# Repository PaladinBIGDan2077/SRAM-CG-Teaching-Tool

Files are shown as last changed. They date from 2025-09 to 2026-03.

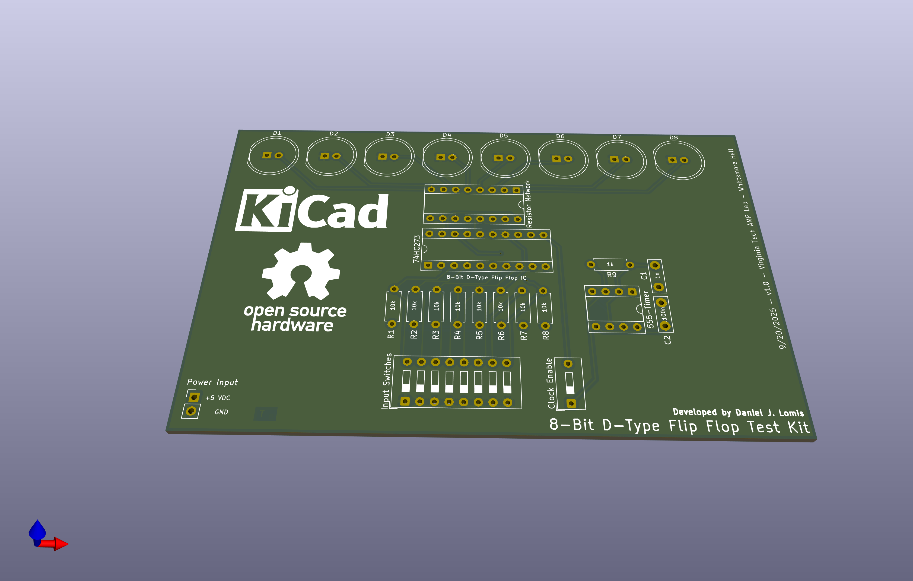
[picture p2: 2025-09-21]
KiCad/Practice/Practice-top.png

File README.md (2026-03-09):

## Members
Daniel J. Lomis, Computer Engineering: Chip-Scale Integration (May 2026)
dlomis1999@vt.edu

## Mentor
Professor Jason S. Thweatt

## Current Status
IN PROGRESS

## Project Overview

This project will demonstrate to the end-user how memory is used to store and read data within a computer, how changing BITs will have an effect on the output of a visualized character. while the unit itself will not be using a centralized processing unit instead the heart of the binary to ask you decoding will be controlled by a character generator ROM made by Fairchild semiconductor. The particular part is a 3257ADC from the late 1970s. The use of vintage components in this particular build helps to take away the layers of abstraction that computers now represent in modern day technology. By simplifying the underlying hardware that has the result of making the overall explanation of its functionality simpler. All plans were originally meant to include a set of early 1980s SRAM moudules. The need to switch to multiple education boards for the final product, made it clear that additional memory was needed as well as a more ample and stable supply of it.

## Educational Value Added

It provides insight to how character generator ROMs work, which were quite common in the days of early home computing. This will lead to a further understanding of ASCII based decoding. Storage of certain bits will allow the character rom to display individual characters on an LED Matrix, which will allow the viewer to write a message on screen letter by letter. A Binary Counter will be used to scroll through memory addresses, and a buffer will be used to display the current data to write to memory, as well as entry of a specific memory address.

## Tasks

Remaining tasks
 • research and implementation of a proper display method for the 8 x 8 matrix
 • research in limitation of the chosen memory modules
 • research and implementation of a binary input method for the memory
 • optional: an implementation to set and reset the memory counter to change specific memory areas that aren't linearly accessed

## Design Decisions

 • the board will be placed on a single PCB smaller than a sheet of standard letter paper
 • the device will be using a 16 VDC power supply going into the power connector on the board. The type of power supply and whether it will be USB-C based has yet to be determined.
 • 
## Design Misc

<!-- Your Text Here. You may work with your mentor on this later when they are assigned -->

## Steps for Documenting Your Design Process

<!-- Your Text Here. You may work with your mentor on this later when they are assigned -->

## BOM + Component Cost

VINTAGE Fairchild 3257ADC Character Generator ROM - $16.37
8X8 LED MATRIX - $10.86
VINTAGE AMD AM9101BPC SRAM Modules 256 x 4 BITS, (two used in series, two in parallel, to increase to 512 X 8 BITS) 512K RAM - $23.97

## Timeline

<!-- Your Text Here. You may work with your mentor on this later when they are assigned -->

## Useful Links

<!-- Your Text Here. You may work with your mentor on this later when they are assigned -->

## Log

<!-- Your Text Here. You may work with your mentor on this later when they are assigned -->

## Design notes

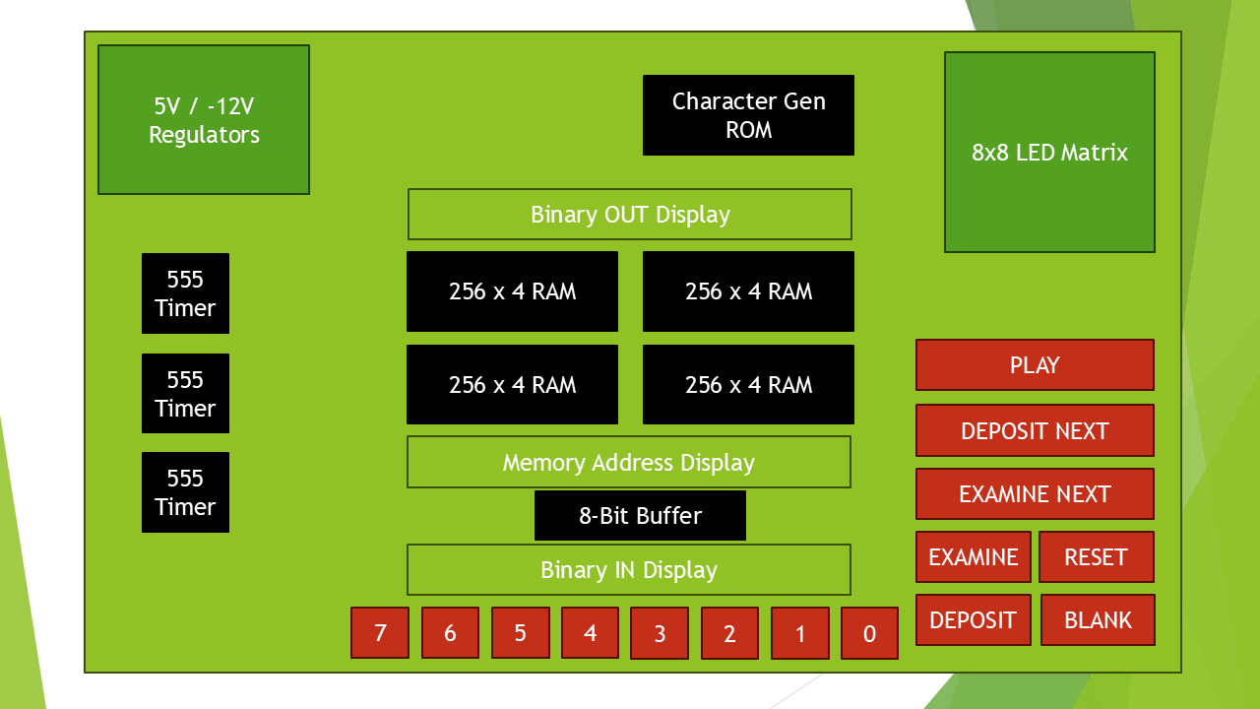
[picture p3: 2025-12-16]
hero.png

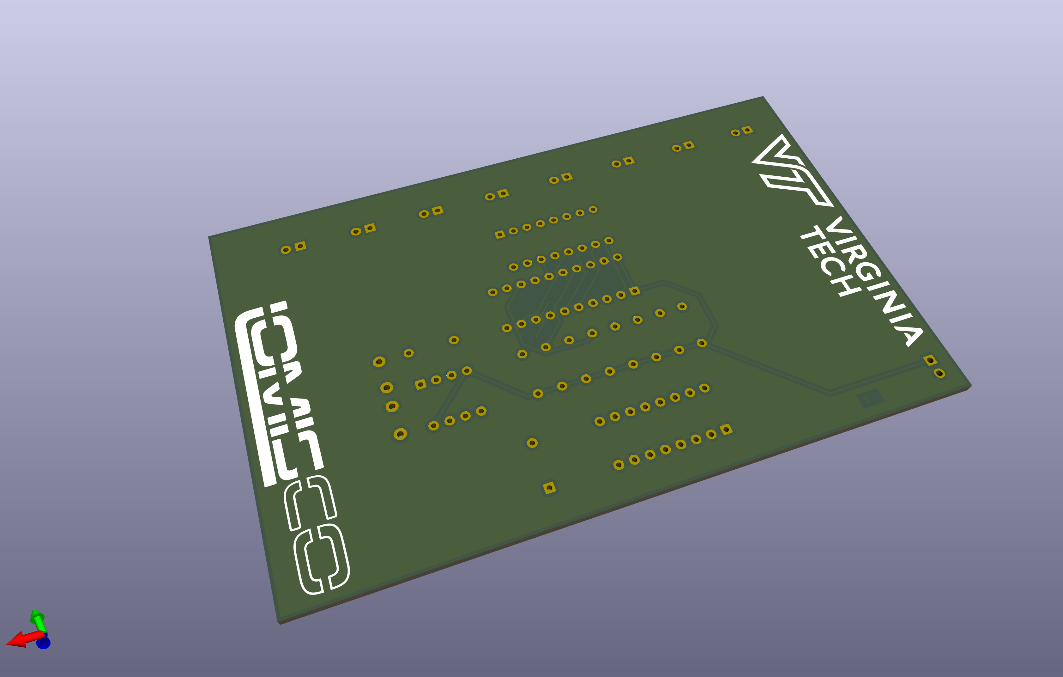
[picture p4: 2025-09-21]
KiCad/Practice/Practice-bottom.png

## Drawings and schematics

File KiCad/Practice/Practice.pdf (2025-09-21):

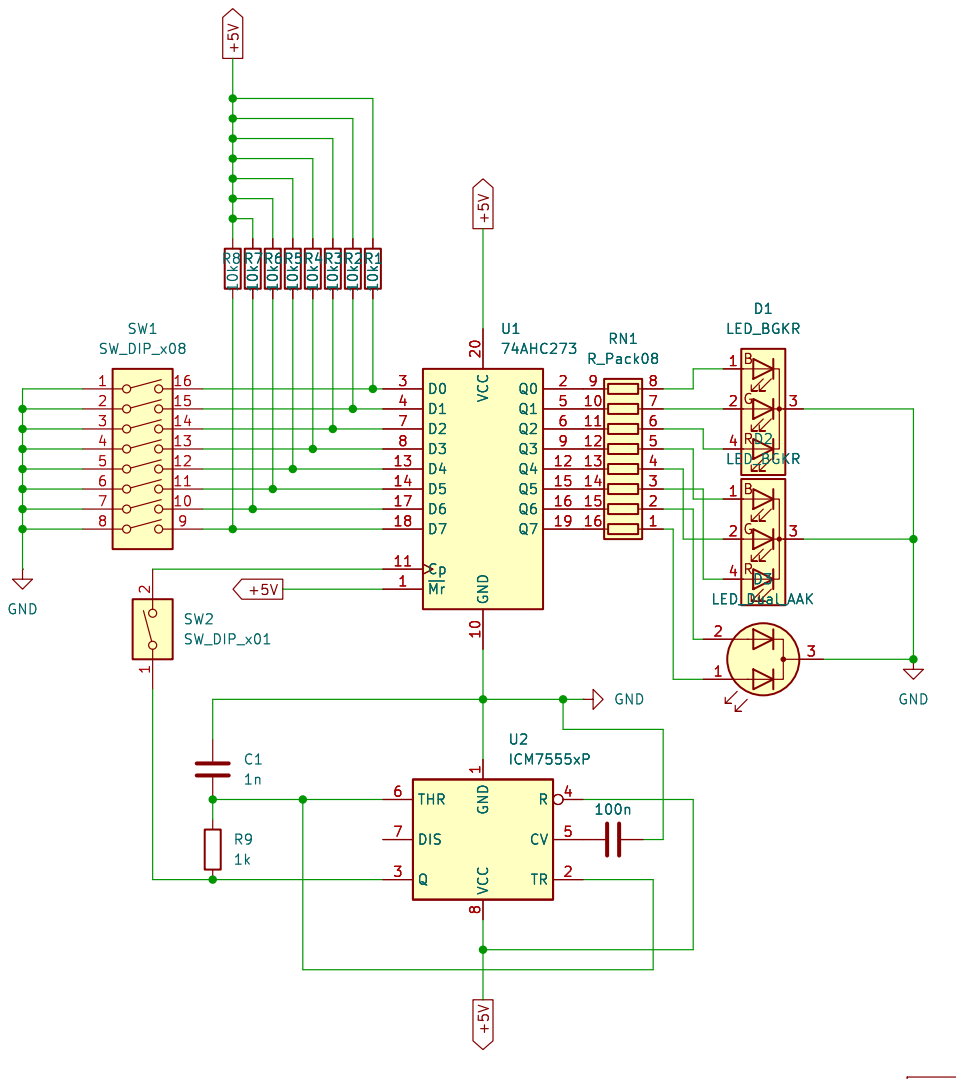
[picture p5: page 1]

10 10 | 7 7
11 11 | 6 6 | | 3 3
13 13 | 4 4 | 1 LED_BGKR LED_BGKR | D2
12 12 | 5 5

14 14 | 3 3
15 15 | 2 2
16 16 | 1 1

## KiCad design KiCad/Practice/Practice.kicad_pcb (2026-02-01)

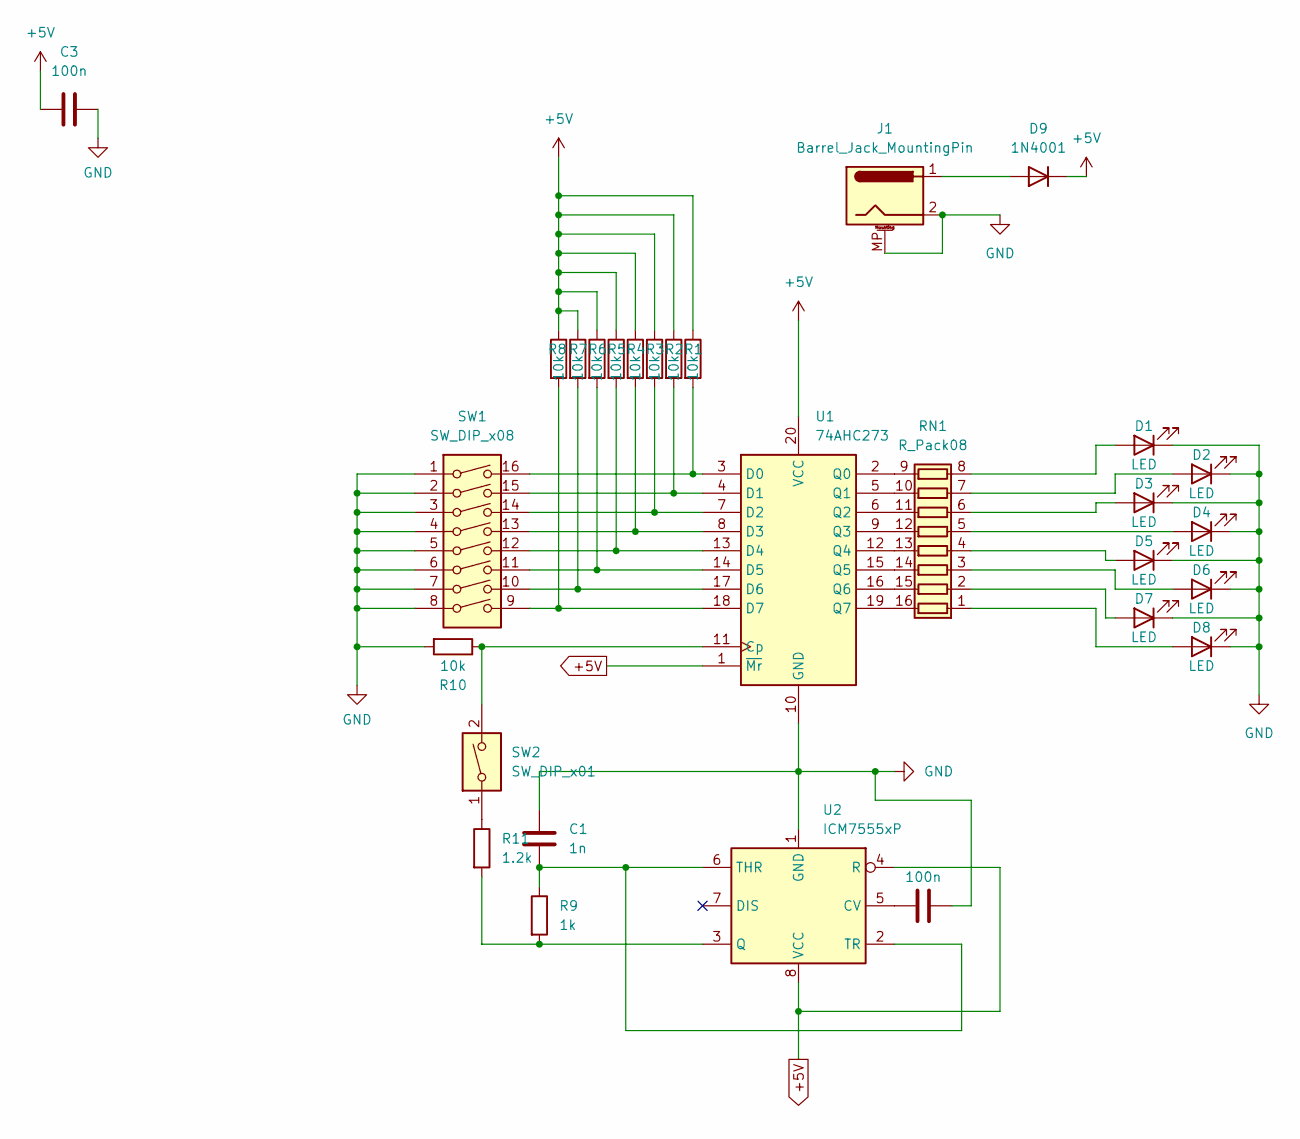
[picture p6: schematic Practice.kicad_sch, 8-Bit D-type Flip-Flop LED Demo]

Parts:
C1: 1n; C_Disc_D7.5mm_W2.5mm_P5.00mm
C2, C3: 100n; C_Disc_D7.5mm_W2.5mm_P5.00mm
D1, D2, D3, D4, D5, D6, D7, D8: LED; LED_D10.0mm
D9: 1N4001; D_DO-41_SOD81_P10.16mm_Horizontal
J1: Barrel_Jack_MountingPin; BarrelJack_CUI_PJ-063AH_Horizontal
R1, R2, R3, R4, R5, R6, R7, R8, R10: 10k; R_Axial_DIN0207_L6.3mm_D2.5mm_P7.62mm_Horizontal
R9: 1k; R_Axial_DIN0207_L6.3mm_D2.5mm_P7.62mm_Horizontal
R11: 1.2k; R_Axial_DIN0207_L6.3mm_D2.5mm_P7.62mm_Horizontal
RN1: R_Pack08; DIP-16_W7.62mm_Socket
SW1: SW_DIP_x08; SW_DIP_SPSTx08_Slide_9.78x22.5mm_W7.62mm_P2.54mm
SW2: SW_DIP_x01; SW_DIP_SPSTx01_Slide_9.78x4.72mm_W7.62mm_P2.54mm
U1: 74AHC273; DIP-20_W7.62mm_Socket
U2: ICM7555xP; DIP-8_W7.62mm_Socket

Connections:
+5V: C3.1, D9.1 (K), R1.1, R2.1, R3.1, R4.1, R5.1, R6.1, R7.1, R8.1, U1.1 (~Mr), U1.20 (VCC), U2.4 (R), U2.8 (VCC)
GND: C1.1, C2.2, C3.2, D1.1 (K), D2.1 (K), D3.1 (K), D4.1 (K), D5.1 (K), D6.1 (K), D7.1 (K), D8.1 (K), J1.2, J1.MP (MountPin), R10.2, SW1.1, SW1.2, SW1.3, SW1.4, SW1.5, SW1.6, SW1.7, SW1.8, U1.10 (GND), U2.1 (GND)
unnamed: D1.2 (A), RN1.8 (R8.1)
unnamed: D2.2 (A), RN1.7 (R7.1)
unnamed: D3.2 (A), RN1.6 (R6.1)
unnamed: D4.2 (A), RN1.5 (R5.1)
unnamed: D5.2 (A), RN1.4 (R4.1)
unnamed: D6.2 (A), RN1.3 (R3.1)
unnamed: D7.2 (A), RN1.2 (R2.1)
unnamed: D8.2 (A), RN1.1 (R1.1)
unnamed: D9.2 (A), J1.1
unnamed: R11.1, SW2.1
unnamed: RN1.16 (R1.2), U1.19 (Q7)
unnamed: RN1.15 (R2.2), U1.16 (Q6)
unnamed: RN1.14 (R3.2), U1.15 (Q5)
unnamed: RN1.13 (R4.2), U1.12 (Q4)
unnamed: RN1.12 (R5.2), U1.9 (Q3)
unnamed: RN1.11 (R6.2), U1.6 (Q2)
unnamed: RN1.10 (R7.2), U1.5 (Q1)
unnamed: RN1.9 (R8.2), U1.2 (Q0)
unnamed: R10.1, SW2.2, U1.11 (Cp)
unnamed: R1.2, SW1.16, U1.3 (D0)
unnamed: R2.2, SW1.15, U1.4 (D1)
unnamed: R3.2, SW1.14, U1.7 (D2)
unnamed: R4.2, SW1.13, U1.8 (D3)
unnamed: R5.2, SW1.12, U1.13 (D4)
unnamed: R6.2, SW1.11, U1.14 (D5)
unnamed: R7.2, SW1.10, U1.17 (D6)
unnamed: R8.2, SW1.9, U1.18 (D7)
unnamed: C2.1, U2.5 (CV)
unnamed: R9.2, R11.2, U2.3 (Q)
unnamed: C1.2, R9.1, U2.2 (TR), U2.6 (THR)

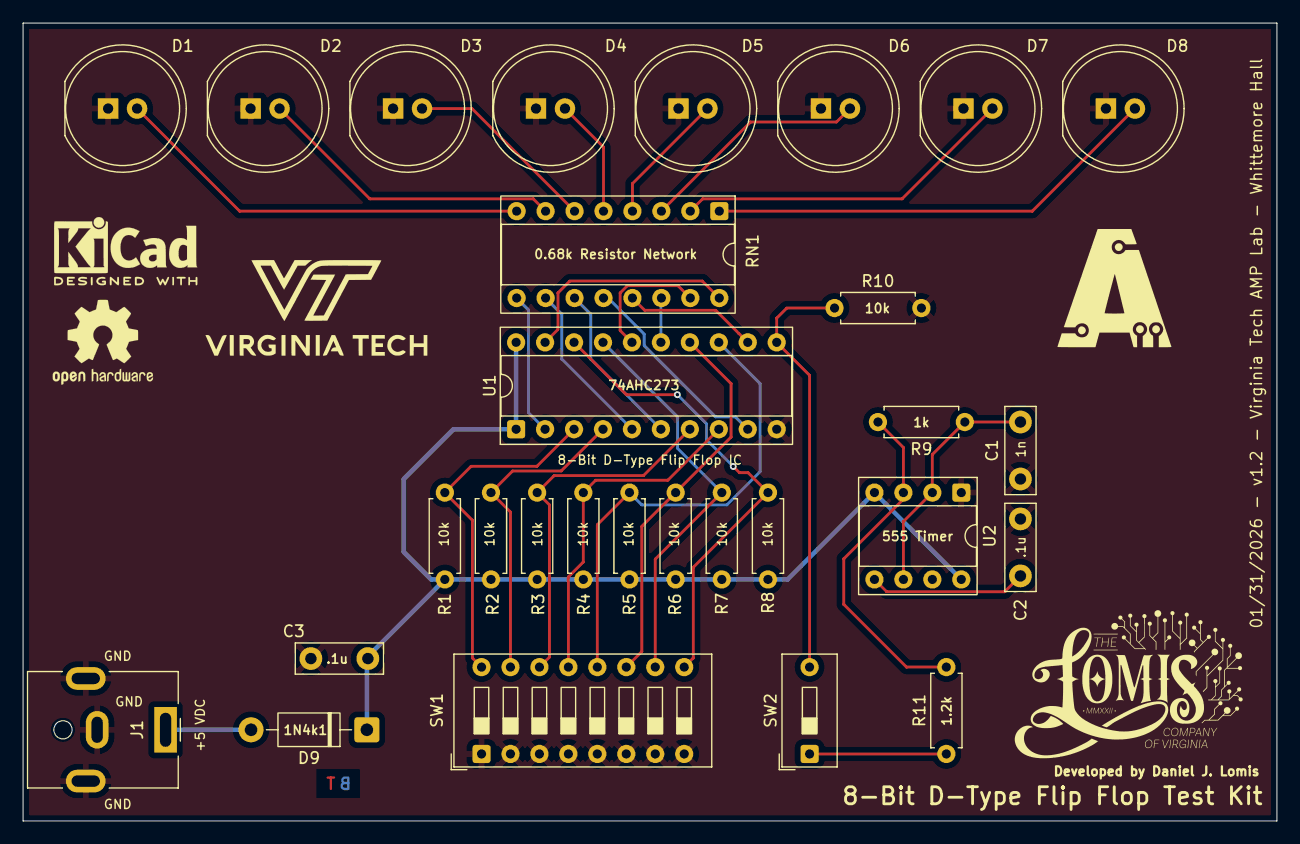
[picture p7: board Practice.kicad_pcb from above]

Board: 4 copper layers, 110.0 x 70.0 mm, 29 parts (0 on the bottom side), 32 nets.

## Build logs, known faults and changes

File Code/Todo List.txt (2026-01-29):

Completed:

Raster for 8x8 LED Matrix (1/29/2026)
Basic TTL Understanding (12/03/2025)
Pull ups, Pull Downs, proper grounding, proper active high and active low connections (1/29/2026)

Still Need To Do:

Make the Counter reset after the blanking interval passes by, which would be two pulses after the 5th row of the Letter (the underscores pictured here)...
X---X__
-X-X-__
--X--__
-X-X-__
X---X__
-----__

Counter only seems to count up every other rising edge, look into this.
Find a better datasheet for the ADC3257
Find a cooling solution for the CG

PCB Practice 8-Bit Memory Concept (This Weekend, 1.31.2026)
-Update the Schematic for use at one of the chinese PCB fabs
-Make sure the parts list is ready
-ADD THE APPLE IIE RIFA CAP TO THE LIST

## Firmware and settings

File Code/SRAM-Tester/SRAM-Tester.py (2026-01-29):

from machine import Pin
import time

# Pin definitions
A0 = Pin(0, Pin.OUT)
A1 = Pin(1, Pin.OUT)
A2 = Pin(2, Pin.OUT)
A3 = Pin(3, Pin.OUT)
A4 = Pin(4, Pin.OUT)
A5 = Pin(5, Pin.OUT)
A6 = Pin(6, Pin.OUT)
A7 = Pin(7, Pin.OUT)

DI1 = Pin(8, Pin.OUT)
DI2 = Pin(9, Pin.OUT)
DI3 = Pin(10, Pin.OUT)
DI4 = Pin(11, Pin.OUT)

DO1 = Pin(12, Pin.IN, Pin.PULL_DOWN)
DO2 = Pin(13, Pin.IN, Pin.PULL_DOWN)
DO3 = Pin(14, Pin.IN, Pin.PULL_DOWN)
DO4 = Pin(15, Pin.IN, Pin.PULL_DOWN)

CE1 = Pin(16, Pin.OUT, value=1)
CE2 = Pin(17, Pin.OUT, value=0)
WE = Pin(18, Pin.OUT, value=1)
OD = Pin(19, Pin.OUT, value=1)

# Put pins in lists for easy access
address_pins = [A0, A1, A2, A3, A4, A5, A6, A7]
data_in_pins = [DI1, DI2, DI3, DI4]
data_out_pins = [DO1, DO2, DO3, DO4]

def set_address(addr):
    """Set address on A0-A7"""
    for i in range(8):
        bit = (addr >> i) & 1
        address_pins[i].value(bit)

def set_data_in(value):
    """Set data on DI1-DI4"""
    for i in range(4):
        bit = (value >> i) & 1
        data_in_pins[i].value(bit)

def get_data_out():
    """Read data from DO1-DO4"""
    value = 0
    for i in range(4):
        bit = data_out_pins[i].value()
        value |= (bit << i)
    return value

def disable_chip():
    """Disable the chip"""
    CE1.value(1)
    CE2.value(0)
    OD.value(1)
    WE.value(1)

def enable_chip_for_write():
    """Enable chip for writing"""
    CE1.value(0)  # LOW = enabled
    CE2.value(1)  # HIGH = enabled
    WE.value(0)   # LOW = write mode
    OD.value(1)   # HIGH = output disabled

def enable_chip_for_read():
    """Enable chip for reading"""
    CE1.value(0)  # LOW = enabled
    CE2.value(1)  # HIGH = enabled
    WE.value(1)   # HIGH = read mode
    OD.value(0)   # LOW = output enabled

def write_nibble(addr, data):
    """Write 4-bit data to address"""
    # Disable chip first
    disable_chip()
    time.sleep_us(10)
    
    # Set address and data
    set_address(addr)
    set_data_in(data)
    time.sleep_us(10)
    
    # Enable for write
    enable_chip_for_write()
    time.sleep_us(10)
    
    # Hold write pulse
    WE.value(0)
    time.sleep_us(10)
    
    # End write
    WE.value(1)
    time.sleep_us(10)
    
    # Disable chip
    disable_chip()
    set_data_in(0)

def read_nibble(addr):
    """Read 4-bit data from address"""
    # Disable chip first
    disable_chip()
    time.sleep_us(10)
    
    # Set address
    set_address(addr)
    time.sleep_us(10)
    
    # Enable for read
    enable_chip_for_read()
    time.sleep_us(10)
    
    # Read data
    data = get_data_out()
    
    # Disable chip
    disable_chip()
    
    return data

def test_single_address():
    """Test writing and reading at address 0"""
    print("\n=== TEST SINGLE ADDRESS ===")
    
    test_addr = 0x00
    test_data = 0x5  # 0101
    
    print(f"Writing 0x{test_data:X} ({test_data:04b}) to address 0x{test_addr:02X}")
    write_nibble(test_addr, test_data)
    
    print(f"Reading from address 0x{test_addr:02X}")
    read_data = read_nibble(test_addr)
    
    print(f"Read: 0x{read_data:X} ({read_data:04b})")
    
    if read_data == test_data:
        print("✅ PASS: Data matches!")
    else:
        print(f"❌ FAIL: Expected 0x{test_data:X}, got 0x{read_data:X}")

def test_all_addresses():
    """Test all 256 addresses"""
    print("\n=== TEST ALL ADDRESSES ===")
    print("Writing 0101 to all addresses...")
    
    test_data = 0x5
    passed = 0
    
    for addr in range(256):
        write_nibble(addr, test_data)
        read_data = read_nibble(addr)
        
        if read_data == test_data:
            passed += 1
        
        if (addr + 1) % 32 == 0:
            print(f"  Tested {addr + 1}/256 addresses")
    
    print(f"\nResults: {passed}/256 addresses passed")
    
    if passed == 256:
        print("✅ ALL TESTS PASSED!")
    else:
        print(f"❌ {256 - passed} addresses failed")

def monitor_pins():
    """Monitor pin states continuously"""
    print("\n=== PIN MONITOR ===")
    print("Press Ctrl+C to stop")
    print("DO1-DO4 should show random data if chip is powered")
    
    try:
        while True:
            # Put chip in read mode
            enable_chip_for_read()
            
            # Read all pins
            addr_val = 0
            for i in range(8):
                addr_val |= (address_pins[i].value() << i)
            
            data_in_val = 0
            for i in range(4):
                data_in_val |= (data_in_pins[i].value() << i)
            
            data_out_val = get_data_out()
            
            print(f"Addr: 0x{addr_val:02X} | DI: 0x{data_in_val:X} | DO: 0x{data_out_val:X} ({DO4.value()}{DO3.value()}{DO2.value()}{DO1.value()}) | CE1:{CE1.value()} CE2:{CE2.value()} WE:{WE.value()} OD:{OD.value()}")
            time.sleep_ms(500)
            
    except KeyboardInterrupt:
        print("\nStopped monitoring")
        disable_chip()

def main():
    print("AM9101 SRAM TEST")
    print("=" * 40)
    
    # Always start with chip disabled
    disable_chip()
    
    try:
        # First, let's check if we can see any output
        print("\nChecking if chip outputs anything...")
        print("Enabling chip for read at address 0...")
        
        set_address(0x00)
        enable_chip_for_read()
        time.sleep_ms(100)
        
        data = get_data_out()
        print(f"DO pins: {DO4.value()}{DO3.value()}{DO2.value()}{DO1.value()}")
        print(f"Data output: 0x{data:X} ({data:04b})")
        
        disable_chip()
        
        if data == 0 and DO1.value() == 0 and DO2.value() == 0 and DO3.value() == 0 and DO4.value() == 0:
            print("\n⚠️  WARNING: All DO pins are reading 0.")
            print("Possible issues:")
            print("1. Chip not getting 5V power")
            print("2. No level shifters (Pico is 3.3V, chip needs 5V)")
            print("3. OD pin should be LOW (0) for reading")
            print("4. CE1 should be LOW (0) AND CE2 should be HIGH (1)")
        
        # Ask what to do next
        choice = input("\nChoose test:\n1. Single address test\n2. All addresses test\n3. Monitor pins\nEnter choice (1-3): ")
        
        if choice == "1":
            test_single_address()
        elif choice == "2":
            test_all_addresses()
        elif choice == "3":
            monitor_pins()
        else:
            print("Invalid choice")
    
    except Exception as e:
        print(f"Error: {e}")
    
    finally:
        disable_chip()
        print("\nChip disabled. Test complete.")

# Run the test
if __name__ == "__main__":
    main()

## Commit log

2025-09-21 Created first practice PCB
    [Practice-BOTTOM.gbr, Practice-B_Mask.gbr, Practice-B_Paste.gbr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]
2025-09-21 Pushed further updates
    [Practice-BOTTOM.gbr, Practice-B_Mask.gbr, Practice-B_Paste.gbr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]
2026-02-01 Development updates to the LED Demo D-Type Flip Flop Board
    [Practice-B_Mask.gbs, Practice-B_Paste.gbp, Practice-B_Silkscreen.gbo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]
2026-03-09 Update README.md
    Updated description to reflect current progress of project
